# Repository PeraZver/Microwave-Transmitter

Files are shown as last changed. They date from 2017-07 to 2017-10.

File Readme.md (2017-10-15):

# Microwave Transmitter

30 - 6000 MHz 10 dBm Transmitter based on MAX2871 synthesizer. 
Controlled by Teensy 3.2. 

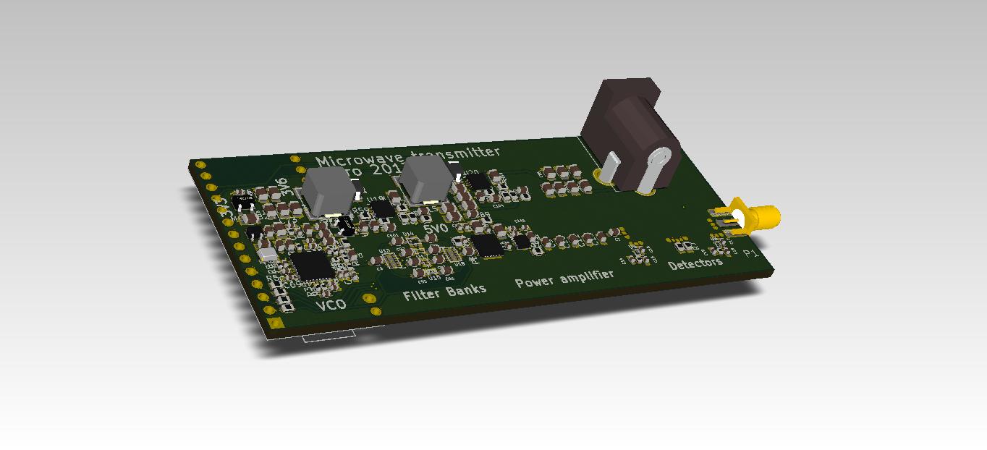
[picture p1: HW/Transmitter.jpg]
MW-Tx


Some parts of the circuit design based on H. Forsten's home made VNA. The microwave transmitter consists of following blocks:

 * **Synthesizer** is based on MAX2871 chip (PLL with integrated VCO) and its loop filter. This guy is able to synthesize frequencies from 25 MHz to 6 GHz.
 * **Filter bank** that makes sure no harmonics are generated in GHz range.
 * **Amplification** block that uses programmable attenuation for the gain control and 12 dB power amplifier TRF37A75.
 * **Coupler and RSSI detectors** that measure emitted and reflected power, of course. 
 * **Teensy 3.2** that controls the synthesizer, selects filter switches, controls the attenuation and AD converts measured power from the RSSI detectors and sends all of data to PC. 
 * **Power supply** that scales 12V input to 5V, 3.6V, 3.3V and 1.8V. 

User's guide of Microwave Transmitter is available at [Github repo's wiki](https://github.com/PeraZver/Microwave-Transmitter/wiki).

Development log of the Microwave Transmitter is documented at [Hackaday.io](https://hackaday.io/project/20350-microwave-transmitter).

Pero, February 2017
(https://www.helentronica.com)

[3d]: https://github.com/PeraZver/Microwave-Transmitter/blob/master/HW/Transmitter.jpg

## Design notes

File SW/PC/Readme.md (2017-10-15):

# Using python script

Just run it, either from the terminal or from your Python IDE. 
In the code, change proper COM port before the run.

Use following commands:
  * `g` - read MAX2871 register content
  * `rt` - read MAX2871 ADC set to temperature readout
  * `rv` - read MAX2871 ADC set to VCO voltage readout
  * `e` - activate RF output
  * `d` - deactivate RF output
  * `px` - sets the power of RF output, where {x} can be 1,2,3 or 4.
  * `fx` - selects the filter, where {x} can be 1,2,3 or 4.

  To change frequency settings, use following commands:
   * `N x` - set integer divider where x is between 16 and 65535.
   * `M x` - set fractional modulus where x is between 2 and 4095.
   * `F x` - set fractional divider where x is between 1 and M.
   * `R x` - set reference divider where x is between 1 and 1023.
   * `D x` - set output divider where x is between 1 and 7.

 Frequency can be easily set by two functions
   * `FINT x` - set sets frequency x in integer mode
   * `FFRAC x` - set sets frequency x in fractional mode

 To set the attentuation, use command:
   * `ATT x` - where x is attenuation in dB from 0 to 32 in steps of 0.25 dB. 

 Special spice is function `sweep`, that enables sweep of every parameter (but will work only with F and N):
  * `sweep x a b dt` - x can be N or F, a is lower limit, b is the upper and dt is time resolution in ms.

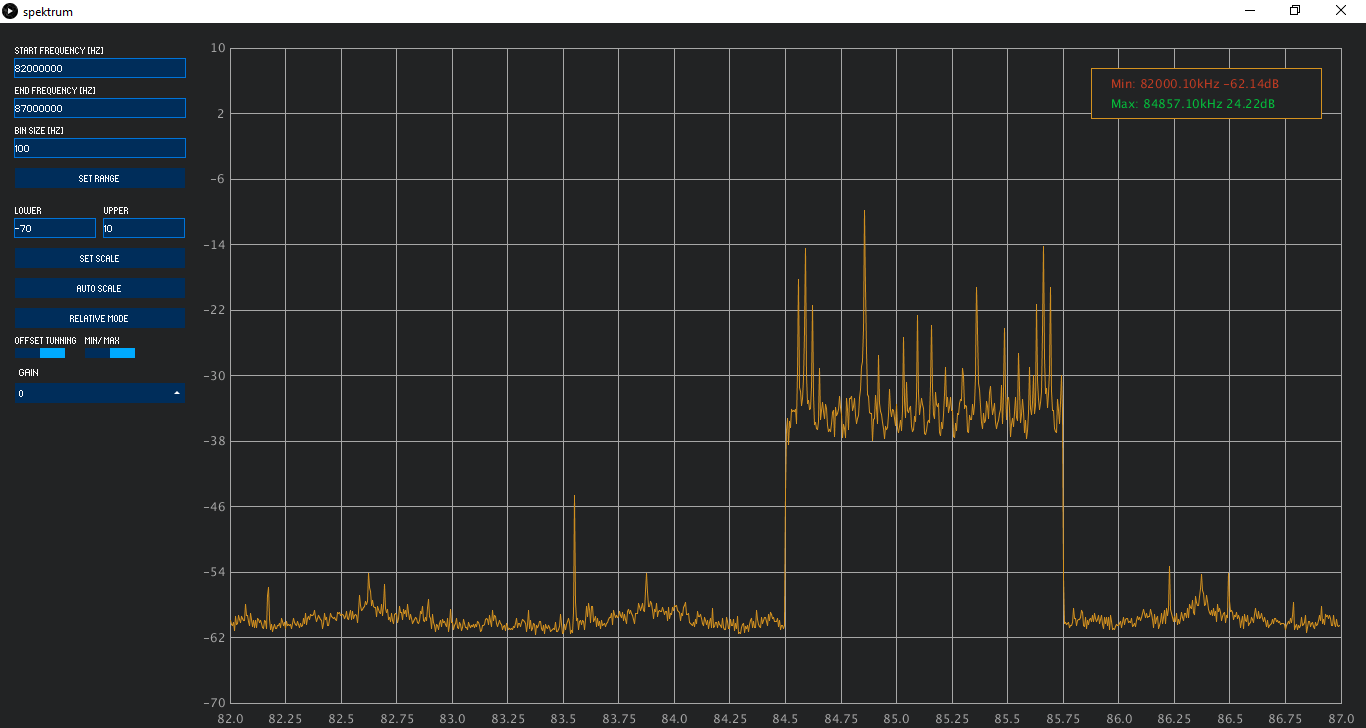
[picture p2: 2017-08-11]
Doc/Screenshots/spektrum_85MHz.png

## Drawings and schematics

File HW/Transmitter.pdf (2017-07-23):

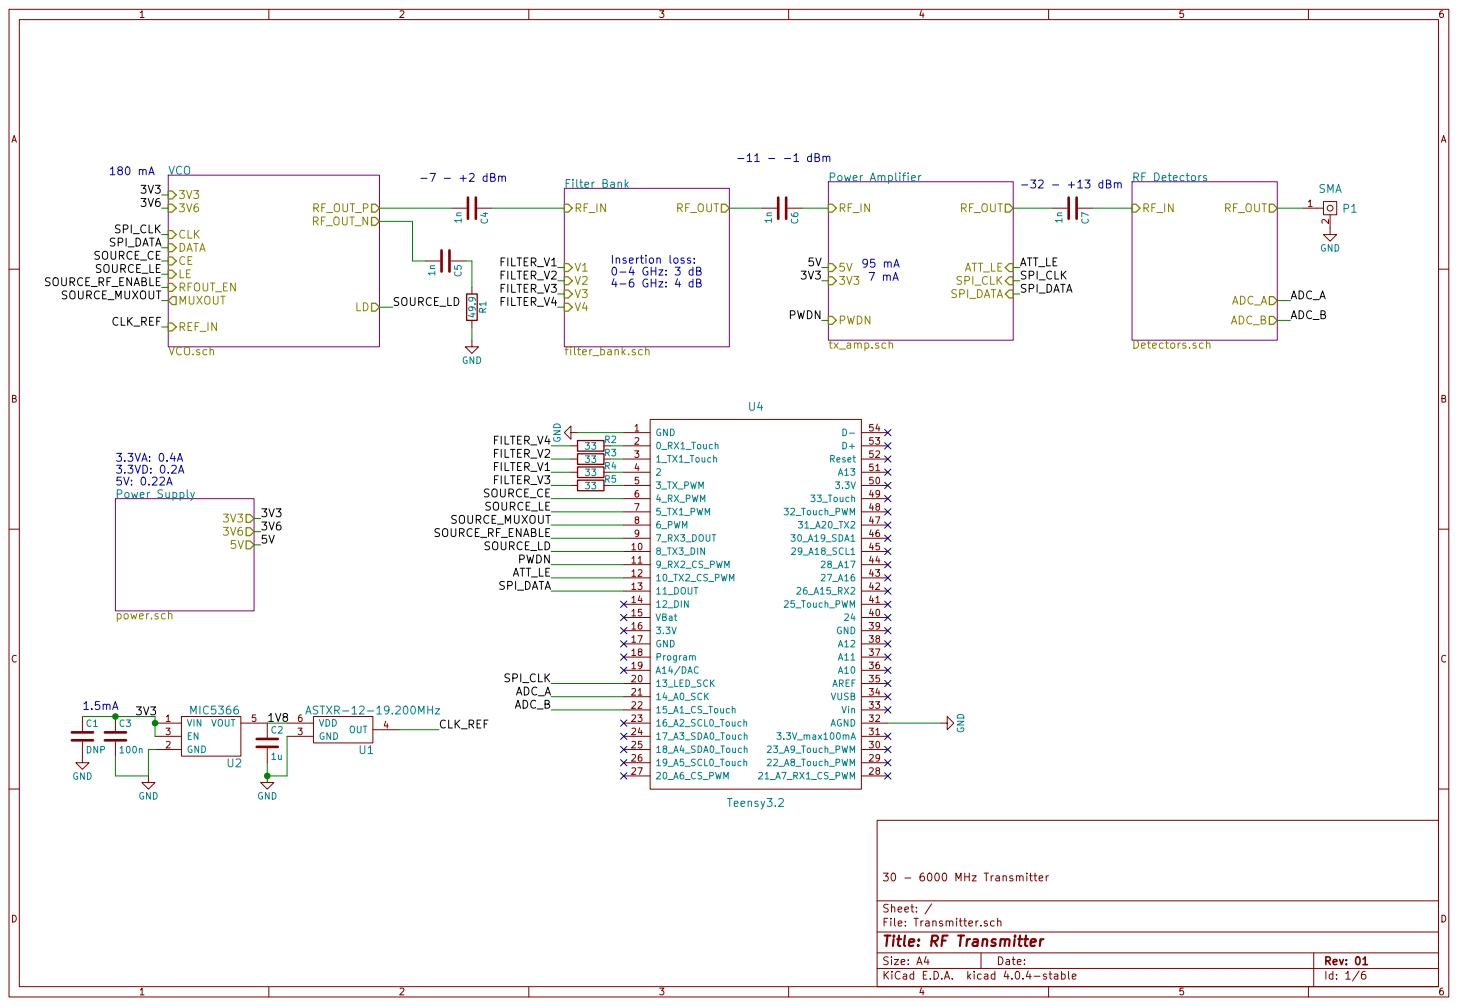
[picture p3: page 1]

Insertion loss: 0-4 GHz: 3 dB
4-6 GHz: 4 dB

Id: 1/6 Title: RF Transmitter File: Transmitter.sch Sheet: / 30 - 6000 MHz Transmitter

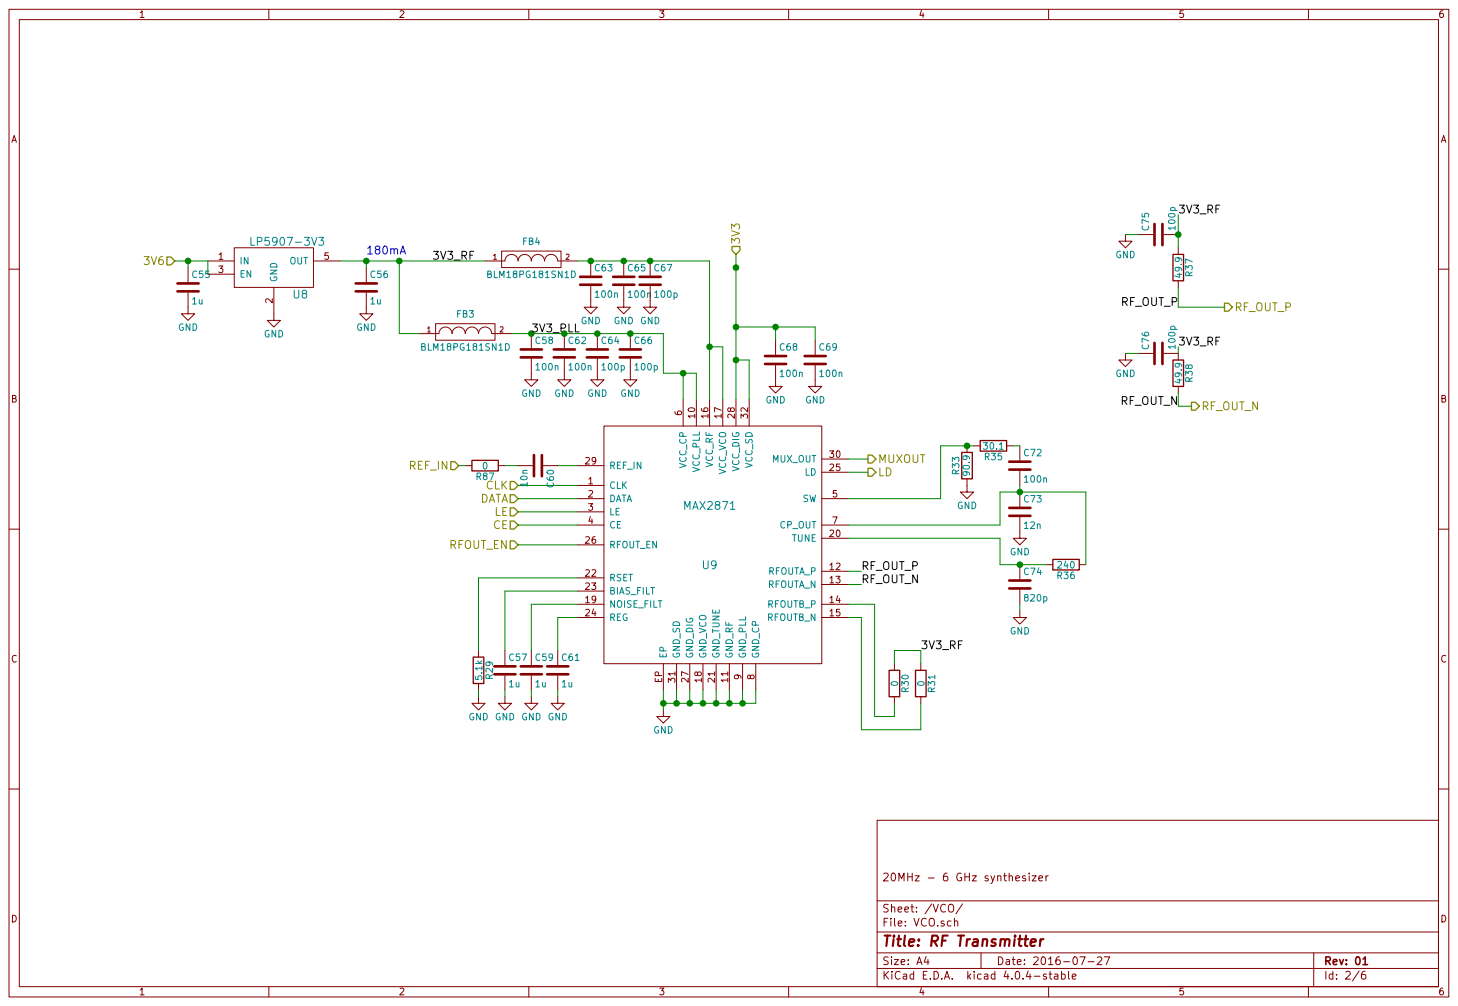
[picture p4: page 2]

100n GND GND GND GND GND

100n 5.1k R29 GND GND GND GND

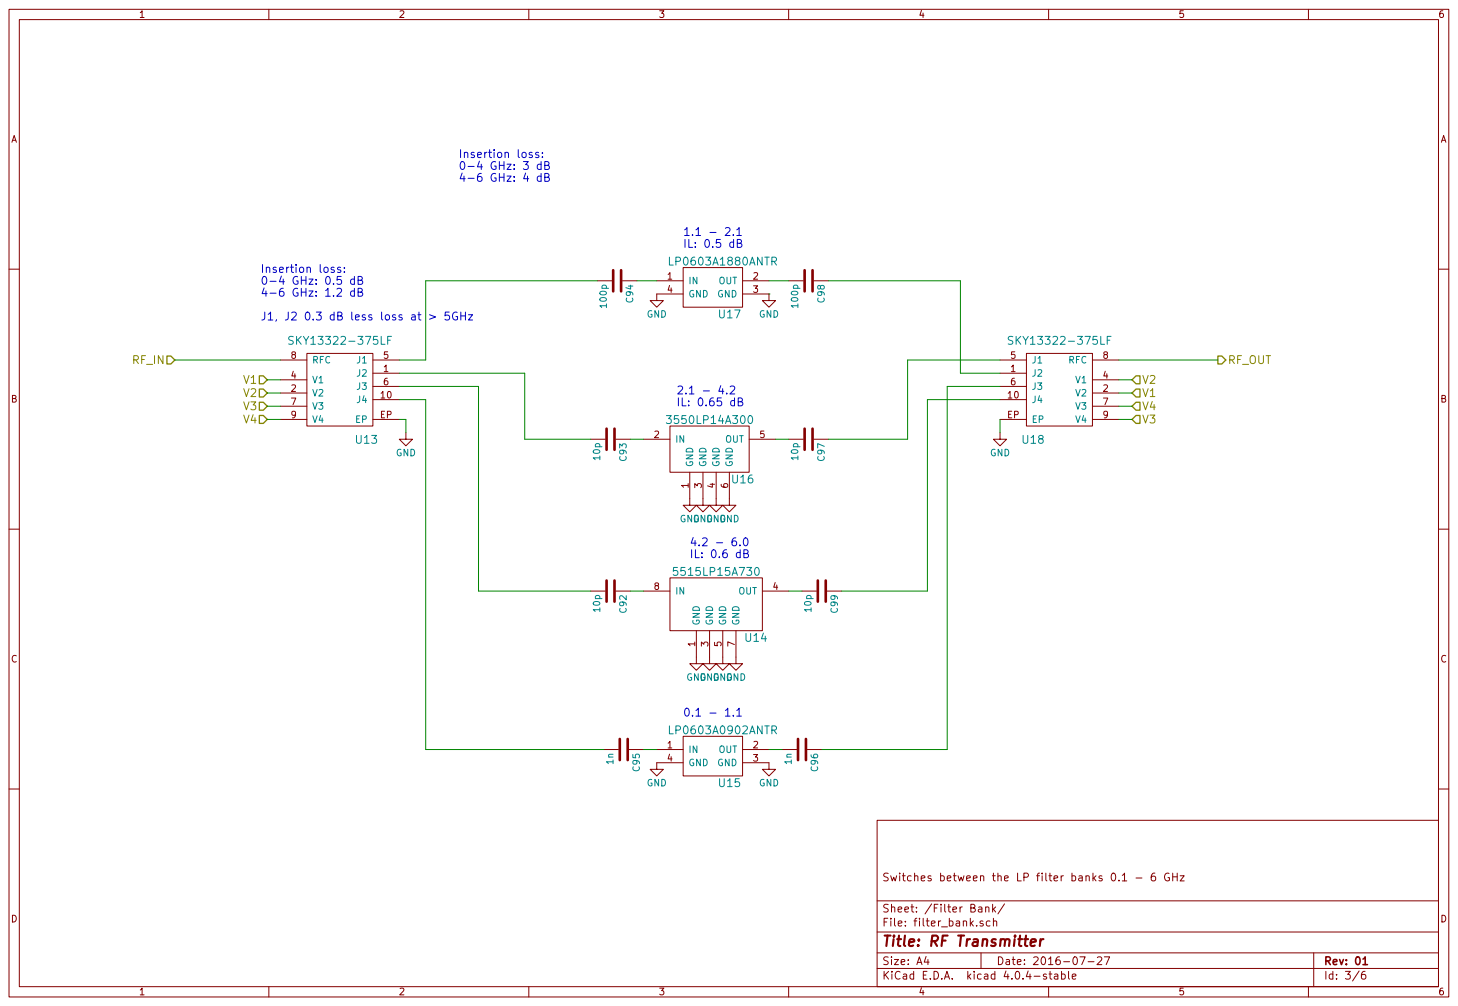
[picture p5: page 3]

Insertion loss: 0-4 GHz: 3 dB
4-6 GHz: 4 dB

Insertion loss: 0-4 GHz: 0.5 dB
4-6 GHz: 1.2 dB
J1, J2 0.3 dB less loss at > 5GHz

File: filter_bank.sch Sheet: /Filter Bank/ Switches between the LP filter banks 0.1 - 6 GHz

Id: 3/6 Title: RF Transmitter

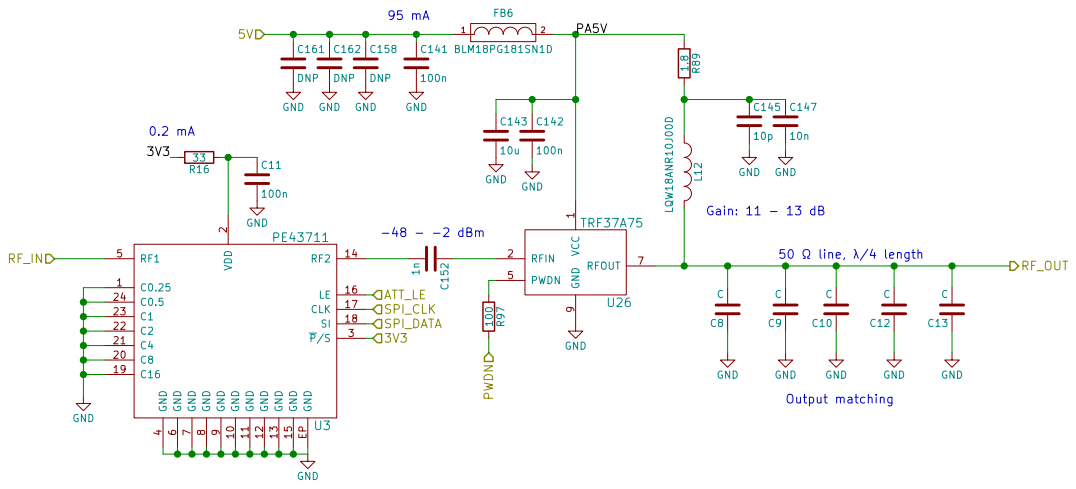
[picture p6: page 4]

1 RFIN 2 PWDN 5 RFOUT 7 GND

9 GND 10 C8 20 GND 11 C4 21 GND 12 C2 22 GND 13 C1 23 RF2 14 C0.5 24 GND 15

Sheet: /Power Amplifier/
File: tx_amp.sch
Id: 4/6 Title: RF Transmitter

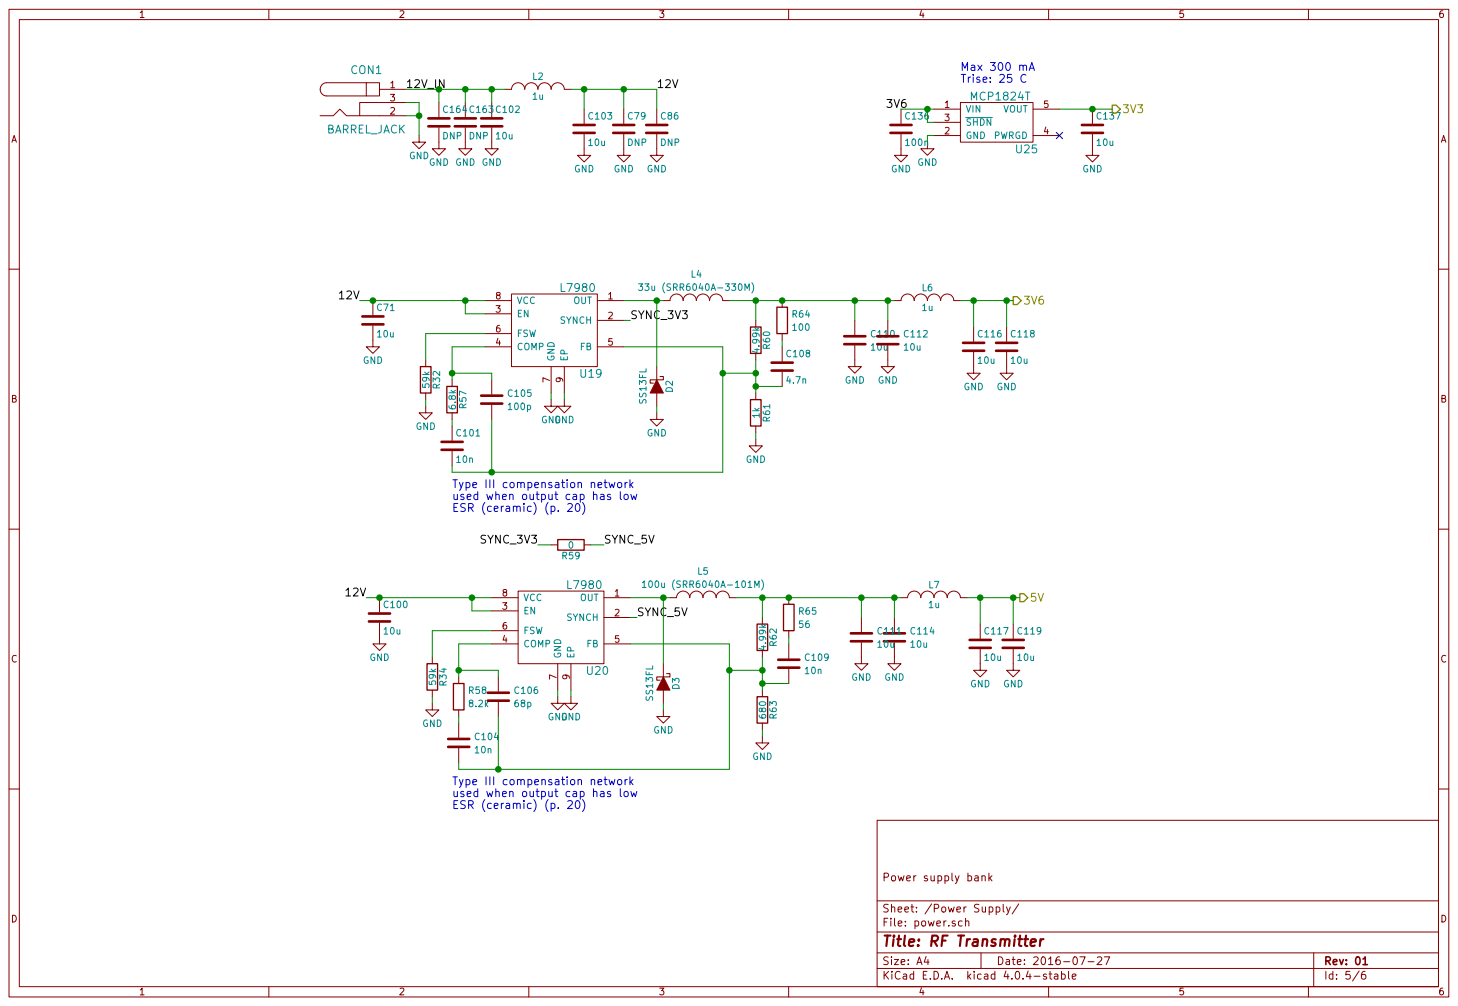
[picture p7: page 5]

C164 DNP GND Type III compensation network

used when output cap has low
ESR (ceramic) (p. 20)

Type III compensation network

Sheet: /Power Supply/
File: power.sch
Id: 5/6 Title: RF Transmitter

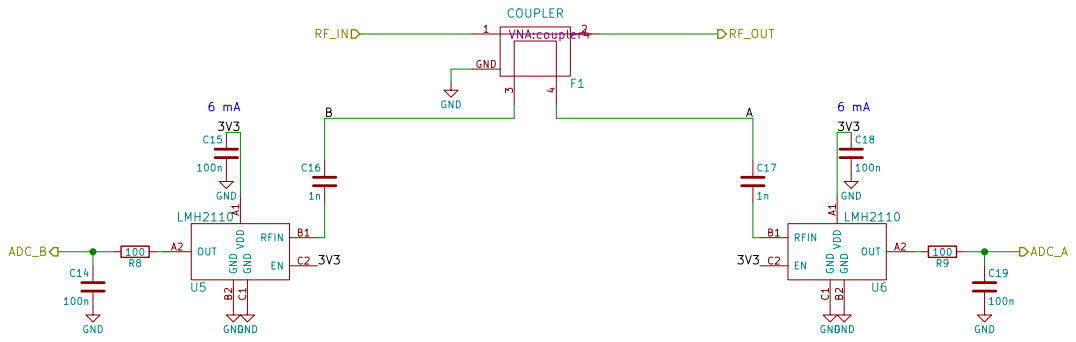
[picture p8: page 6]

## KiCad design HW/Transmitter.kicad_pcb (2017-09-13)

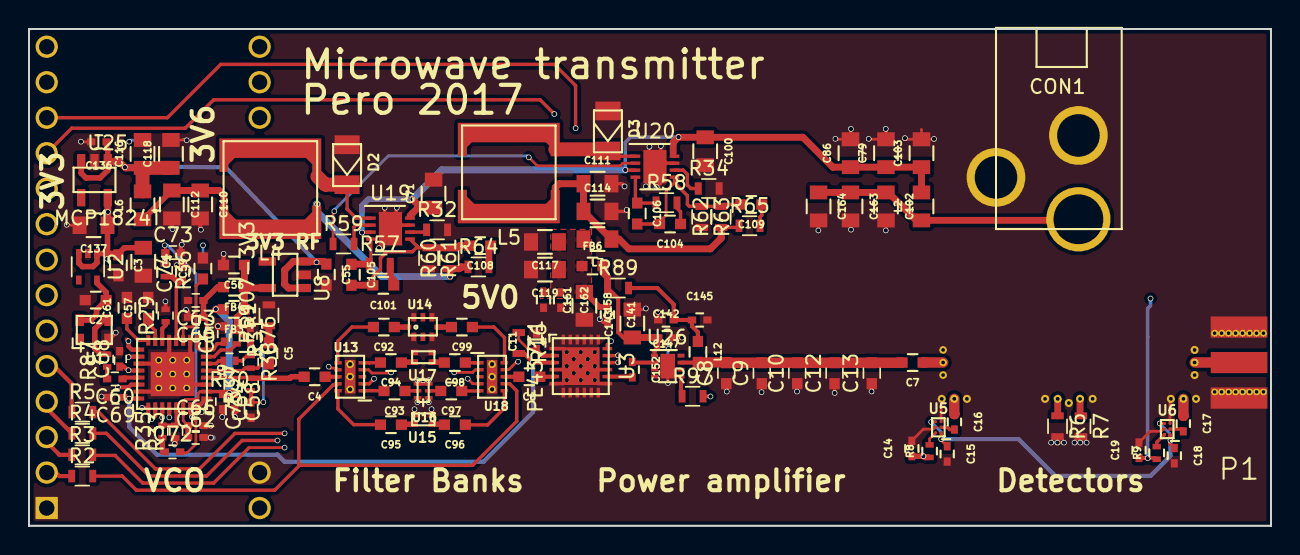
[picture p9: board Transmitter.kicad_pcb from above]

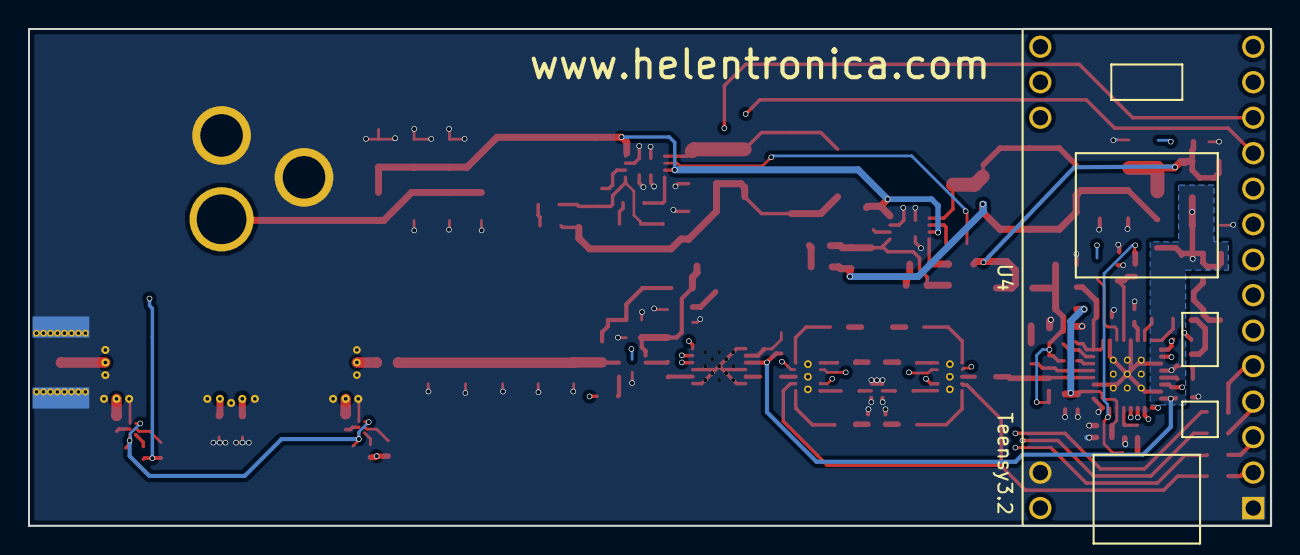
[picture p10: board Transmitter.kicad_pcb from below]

Board: 4 copper layers, 88.9 x 35.6 mm, 144 parts (2 on the bottom side), 98 nets.

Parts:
C1, C79, C86, C158, C163, C164: DNP; C_0805b
C2, C55, C56, C57, C59, C61: 1u; C_0603b
C3: 100n; C_0603b
C4, C5, C6, C7, C95, C96: 1n; C_0603b
C8, C9, C10, C12, C13: C; C_0603
C11, C14, C15, C18, C19, C136, C141, C142: 100n; C_0402b
C16, C17, C152: 1n; C_0402b
C58, C62, C63, C65, C68, C69, C72: 100n; C_0402
C60: 10n; C_0402
C64, C66, C67, C75, C76: 100p; C_0402
C71, C100, C102, C103, C110, C111, C112, C114, C116, C117, C118, C119, C137, C143: 10u; C_0805b
C73: 12n; C_0402
C74: 820p; C_0402
C92, C93, C97, C99: 10p; C_0603b
C94, C98, C105: 100p; C_0603b
C101, C104, C109: 10n; C_0603b
C106: 68p; C_0603b
C108: 4.7n; C_0603b
C145: 10p; C_0402b
C147: 10n; C_0402b
C161, C162: DNP; C_0402b
CON1: BARREL_JACK; EJ508A
D2, D3: SS13FL; SOD-123F
F3: COUPLER; coupler4
FB3, FB4, FB6: BLM18PG181SN1D; C_0603b
L2, L6, L7: 1u; C_0805b
L4: 33u (SRR6040A-330M); SRR6040A
L5: 100u (SRR6040A-101M); SRR6040A
L12: LQW18ANR10J00D; C_0603b
P1: SMA; CONSMA003.062
R1, R6, R7: 49.9; R_0603
R2, R3, R4, R5, R16: 33; R_0603
R8, R9: 100; R_0402b
R29: 5.1k; R_0402
R30, R31, R87: 0; R_0402
R32, R34: 59k; R_0603
R33: 90.9; R_0402
R35: 30.1; R_0402
R36: 240; R_0402
R37, R38: 49.9; R_0402
R57: 6.8k; R_0603
R58: 8.2k; R_0603
R59: 0; R_0603
R60, R62: 4.99k; R_0603
R61: 1k; R_0603
R63: 680; R_0603
R64, R97: 100; R_0603
R65: 56; R_0603
R89: 1.8; R_0603
U1: ASTXR-12-19.200MHz; ASTRX-12
U2: MIC5366; SOT-353_SC-70-5
U3: PE43711; VQFN-24
U4: Teensy3.2; Teensy30_31_32_LC
U5, U6: LMH2110; WFBGA-6
U8: LP5907-3V3; SOT-23-5
U9: MAX2871; TQFN-32
U13, U18: SKY13322-375LF; MLPD-10
U14: 5515LP15A730
U15: LP0603A0902ANTR; LP0603A0902
U16: 3550LP14A300
U17: LP0603A1880ANTR; LP0603A0902
U19, U20: L7980; DFN-8-1EP_3x3mm_Pitch0.5mm
U25: MCP1824T; SOT-23-5
U26: TRF37A75; DFN-8-1EP_2x2mm_Pitch0.5mm

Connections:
/1V8: C2.1, U1.6, U2.5
/3V3: C1.1, C3.1, C68.1, C69.1, C137.1, R16.2, U2.1, U2.3, U3.3, U9.28, U9.32, U25.5
/3V6: C55.1, C116.1, C118.1, C136.1, L6.2, U8.1, U8.3, U25.1, U25.3
/5V: C117.1, C119.1, C141.1, C158.1, C161.1, C162.1, FB6.1, L7.2
/ADC_A: C19.1, R9.1, U4.21
/ADC_B: C14.1, R8.1, U4.22
/ATT_LE: U3.16, U4.12
/CLK_REF: R87.2, U1.4
/FILTER_V1: R4.2, U13.4, U18.2
/FILTER_V2: R3.2, U13.2, U18.4
/FILTER_V3: R5.2, U13.7, U18.9
/FILTER_V4: R2.2, U13.9, U18.7
/Filter Bank/RF_IN: C4.1, U13.8
/Filter Bank/RF_OUT: C6.2, U18.8
/PWDN: R97.2, U4.11
/Power Amplifier/PA5V: C142.1, C143.1, FB6.2, R89.1, U26.1
/Power Amplifier/RF_IN: C6.1, U3.5
/Power Amplifier/RF_OUT: C7.2, C8.2, C9.2, C10.2, C12.2, C13.2, L12.2, U26.7
/Power Supply/12V: C71.1, C79.1, C86.1, C100.1, C103.1, L2.2, U19.3, U19.8, U20.3, U20.8
/Power Supply/12V_IN: C102.1, C163.1, C164.1, CON1.1, L2.1
/Power Supply/SYNC_3V3: R59.2, U19.2
/Power Supply/SYNC_5V: R59.1, U20.2
/RF Detectors/3V3: C15.1, C18.1, U5.A1, U5.C2, U6.A1, U6.C2
/RF Detectors/A: C17.1, F3.6
/RF Detectors/B: C16.1, F3.3
/RF Detectors/RF_IN: C7.1, F3.1
/RF Detectors/RF_OUT: F3.2, P1.1
/SOURCE_CE: U4.6, U9.4
/SOURCE_LD: U4.10, U9.25
/SOURCE_LE: U4.7, U9.3
/SOURCE_MUXOUT: U4.8, U9.30
/SOURCE_RF_ENABLE: U4.9, U9.26
/SPI_CLK: U3.17, U4.20, U9.1
/SPI_DATA: U3.18, U4.13, U9.2
/VCO/3V3_PLL: C58.1, C62.1, C64.1, C66.1, FB3.2, U9.6, U9.10
/VCO/3V3_RF: C56.1, C75.2, C76.2, FB3.1, FB4.1, R30.1, R31.1, R37.1, R38.1, U8.5
/VCO/RF_OUT_N: C5.2, R38.2, U9.13
/VCO/RF_OUT_P: C4.2, R37.2, U9.12
GND: C1.2, C2.2, C3.2, C8.1, C9.1, C10.1, C11.2, C12.1, C13.1, C14.2, C15.2, C18.2, C19.2, C55.2, C56.2, C57.2, C58.2, C59.2, C61.2, C62.2, C63.2, C64.2, C65.2, C66.2, C67.2, C68.2, C69.2, C71.2, C73.2, C74.2, C75.1, C76.1, C79.2, C86.2, C100.2, C102.2, C103.2, C110.2, C111.2, C112.2, C114.2, C116.2, C117.2, C118.2, C119.2, C136.2, C137.2, C141.2, C142.2, C143.2, C145.2, C147.2, C158.2, C161.2, C162.2, C163.2, C164.2, CON1.2, CON1.3, D2.2, D3.2, F3.GND, P1.2, R1.2, R6.2, R7.2, R29.2, R32.2, R33.1, R34.2, R61.2, R63.2, U1.3, U2.2, U3.1, U3.4, U3.6, U3.7, U3.8, U3.9, U3.10, U3.11, U3.12, U3.13, U3.15, U3.19, U3.20, U3.21, U3.22, U3.23, U3.24, U3.EP, U4.1, U4.32, U5.B2, U5.C1, U6.B2, U6.C1, U8.2, U9.8, U9.9, U9.11, U9.18, U9.21, U9.27, U9.31, U9.EP, U13.EP, U14.1, U14.3, U14.5, U14.7, U15.3, U15.4, U16.1, U16.3, U16.4, U16.6, U17.3, U17.4, U18.EP, U19.7, U19.9, U20.7, U20.9, U25.2, U26.9
unnamed: C5.1, R1.1
unnamed: C11.1, R16.1, U3.2
unnamed: C16.2, U5.B1
unnamed: C17.2, U6.B1
unnamed: C57.1, U9.23
unnamed: C59.1, U9.19
unnamed: C60.1, U9.29
unnamed: C60.2, R87.1
unnamed: C61.1, U9.24
unnamed: C63.1, C65.1, C67.1, FB4.2, U9.16, U9.17
unnamed: C72.1, R35.1
unnamed: C72.2, C73.1, R36.1, U9.7
unnamed: C74.1, R36.2, U9.20
unnamed: C92.1, U14.8
unnamed: C92.2, U13.6
unnamed: C93.1, U16.2
unnamed: C93.2, U13.1
unnamed: C94.1, U17.1
unnamed: C94.2, U13.5
unnamed: C95.1, U15.1
unnamed: C95.2, U13.10
unnamed: C96.1, U18.6
unnamed: C96.2, U15.2
unnamed: C97.1, U18.5
unnamed: C97.2, U16.5
unnamed: C98.1, U18.1
unnamed: C98.2, U17.2
unnamed: C99.1, U18.10
unnamed: C99.2, U14.4
unnamed: C101.1, R57.2
unnamed: C101.2, C105.2, C108.2, R60.2, R61.1, U19.5
unnamed: C104.1, R58.2
unnamed: C104.2, C106.2, C109.2, R62.2, R63.1, U20.5
unnamed: C105.1, R57.1, U19.4
unnamed: C106.1, R58.1, U20.4
unnamed: C108.1, R64.2
unnamed: C109.1, R65.2
unnamed: C110.1, C112.1, L4.2, L6.1, R60.1, R64.1
unnamed: C111.1, C114.1, L5.2, L7.1, R62.1, R65.1
unnamed: C145.1, C147.1, L12.1, R89.2
unnamed: C152.1, U26.2
unnamed: C152.2, U3.14
unnamed: D2.1, L4.1, U19.1
unnamed: D3.1, L5.1, U20.1
unnamed: F3.4, R6.1
unnamed: F3.5, R7.1
unnamed: R2.1, U4.2
unnamed: R3.1, U4.3
unnamed: R4.1, U4.4
unnamed: R5.1, U4.5
unnamed: R8.2, U5.A2
unnamed: R9.2, U6.A2
unnamed: R29.1, U9.22
unnamed: R30.2, U9.14
unnamed: R31.2, U9.15
unnamed: R32.1, U19.6
unnamed: R33.2, R35.2, U9.5
unnamed: R34.1, U20.6
unnamed: R97.1, U26.5

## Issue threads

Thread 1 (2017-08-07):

Switch not working in position 1

PeraZver, 2017-08-07:
Input switch SKY13322-375LF behaves weirdly when switched to position 1. Otherwise it works fine. Output switch no issues. Both issues weird when control signals are all low.

PeraZver, 2017-09-06:
Switch resoldered and works fine.

Closed 2017-09-06.

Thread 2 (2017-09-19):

RSSI Detectors not working

PeraZver, 2017-09-19:
I didn't manage to receive any meaningful signal from RSSI outputs. Two possible reasons for this:
a) Bad soldering of 6-ball BGA chips
b) Poor coupling from the main line.

Nothing I can do about it in this revision. In the next one, I'll try to put coupler and RSSI detectors on different board.

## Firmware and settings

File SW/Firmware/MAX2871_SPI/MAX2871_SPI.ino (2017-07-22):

/*  MAX2871 SPI Interface
  
  This example controls an MAX2871 synthesizer.
  
  MAX2871 serial interface contains six write-only and
  one read-only 32-bit registers. 
     
   The circuit:
  * CLK is pin 13
  * DATA OUT is pin 11
  * LE is pin 5
  * DATA IN is pin 12
  * CE is pin 6
  * RF EN is pin 7

 
Pero, June 2017
 
*/


// include the SPI library:
#include <SPI.h>

#define slaveSelectPin 5   //LE or slave select
#define chipEnablePin  4   // (CE)
#define clkPin         13  // clk pin
SPISettings MAX2871_SPISettings(1000000, MSBFIRST, SPI_MODE0);

char incomingChar = 0;  //Serial input

void setup() {
  delay(3000);
  Serial.begin(9600);
  Serial.println("MAX2871 SPI Interface");  
  Serial.println("v0.0");
  Serial.println("Pero, June 2017");
  Serial.println(" ");
  Serial.println(" ");
  // Enable chip
  pinMode(chipEnablePin, OUTPUT);
  digitalWrite(chipEnablePin, HIGH);
    
  // set the slaveSelectPin as an output:
  pinMode (slaveSelectPin, OUTPUT);
  digitalWrite (slaveSelectPin, HIGH);
  
  // initialize SPI:
  SPI.begin(); 
  Serial.println("SPI Initialized");
  
  MAX2871_Init ();
  Serial.println("MAX2871 Initialized");
  
}

void loop() {
  if(Serial.available() > 0) 
    incomingChar = Serial.read();
  
  //incomingChar = 'r';
  switch (incomingChar){
    
    case 'r':    
      MAX2871_Set_MUX(3);  // Set read function on MUX pin
      while(1){
        MAX2871_Read();
        delay(1000);
      }
      break;
      
    default:
      MAX2871_Set_MUX(1);
      delay(2000);
      MAX2871_Set_MUX(2);
      delay(2000);
  }
}

void MAX2871_Init (){
//Upon power-up, the registers should be programmed
//twice with at least a 20ms pause between writes. The first
//write ensures that the device is enabled, and the second
//write starts the VCO selection process. Recommended to
//turn-off the outputs during this sequence and then turn-on
//the outputs using RFA_EN, RFB_EN. 

//Register programming order should be address 0x05,
//0x04, 0x03, 0x02, 0x01, and 0x00. 

 uint32_t regInitValues[6] = {0x00000005, 
                              0x60000004,
                              0x00000003,
                              0x00000002,
                              0x00000001,
                              0x0};

 // Writing 2 times
 for (int j = 0; j < 2; j++){
  for (int i = 0; i < 6; i++)   // 6 write registers
      MAX2871_SPI_tx (regInitValues[i]);  //Everything to 0.
  delay(20);
  }
      
}

void MAX2871_Read(){
  /*
    Register 0x06 can be read back through the MUX pin.
    The user must set MUX (register 5, bit 18 and register
    2, bits 28:26) = 1100. To begin the read sequence, set
    LE to logic-low, send 32 periods of CLK, and set LE to
    logic-high. While the CLK is running, the DATA pin can
    be held at logic-high or logic-low for 29 clocks, but the
    last 3 bits must be 110 to indicate register 6, then set LE
    back to logic-high after the 32nd clock. Finally, send 1
    period of the clock. The MSB of register 0x06 appears
    after the rising edge of the next clock and continues to
    shift out for the next 29 clock cycles (Figure 2). After the
    LSB of register 0x06 has been read, the user can reset
    MUX register = 0000.
   */
   uint32_t spi_data = 0;
   uint8_t spi_packet[4] = {0}; 
   signed char i;
   Serial.println("Reading data from MAX2871.");
   
   MAX2871_SPI_tx(spi_data | 6);   // "... last 3 bits must be 110 to indicate register 6." 

   SPI.beginTransaction(MAX2871_SPISettings);  // start new clock sequence. No need to change SS to low.
   for ( i = 0; i < 4; i++)   {
       spi_packet[i] = SPI.transfer(0x06);   // read from SPI shift register 4 times
   }
   SPI.endTransaction();    
  
  Serial.println("Data read:");
  for ( i = 0; i < 4; i++){
     Serial.println(spi_packet[i], HEX);
     spi_data |= spi_packet[i];  
     if ( i != 3)
         spi_data = spi_data << 8;
  }
  Serial.println(spi_data << 2, HEX);
  Serial.println("Reading done!");   
  //MAX2871_Set_MUX(0);  // Reset MUX pin
  
  
}

void MAX2871_Set_MUX(byte MUXSet){
  
/* Bits MUX[3:0] set the MUX pin.
 *  0001: VDD
 *  0010: GND
 *  1100: SPI read operation
 *  
 *  MUX[3] is bit 18 in reg5, and MUX[2:0] are bits 28:26 in reg2.
 */

 uint32_t spi_data = 0; // 32-bits for SPI consist of 29 data bits and 3 address bits.
 
 switch( MUXSet ){

    case 0:  //Set MUX to High Z
         Serial.println("setting MUX to High Z ...");
         // Set all to zero
         MAX2871_SPI_tx( spi_data | 0x02);
         MAX2871_SPI_tx( spi_data | 0x05);
         break;
         
    case 1:   // Set MUX to VDD
         Serial.println("setting MUX to VDD ...");
         spi_data |= (1 << 26);
         MAX2871_SPI_tx(spi_data | 0x02);
         break;
         
    case 2:  // Set MUX to GND
         Serial.println("setting MUX to GND ...");
         spi_data |= (1<<27);
         MAX2871_SPI_tx(spi_data | 0x02);
         break;
         
    default:  //Set MUX to "read"
         Serial.println("setting MUX to SPI read ...");
         spi_data |= (1<<18);
         MAX2871_SPI_tx(spi_data | 0x05);         
         spi_data = 0;    
         spi_data |= (1<<28);
         MAX2871_SPI_tx(spi_data | 0x02);
         
 }
}

void MAX2871_SPI_tx(uint32_t spi_data){
  /*
  This function takes 32-bit data and parses it on four 8-bit packets that Teensy transmitts. The 29 most-significant
  bits (MSBs) are data, and the three least-significant bits (LSBs) are the register address. 
   */

    signed char i = 0;
    uint8_t spi_package[4] = {0};
    // store 32-bit integer into 4 bytes
    for ( i = 0; i < 4; i++) {
       spi_package[i] = (spi_data & (0xFF << 8*i)) >> ( 8*i ) ;
       //Serial.println(spi_package[i], HEX);
    }
    
    Serial.println("Sending data: "); 
    Serial.println(spi_data, HEX);
    digitalWrite(slaveSelectPin,LOW);   
    SPI.beginTransaction(MAX2871_SPISettings);
     
    for ( i = 3; i >= 0; i--)
         SPI.transfer(spi_package[i]); 
          
    digitalWrite(slaveSelectPin,HIGH);
    SPI.endTransaction();  
    Serial.println("SPI transmission done!");
    delay(20);
}
  

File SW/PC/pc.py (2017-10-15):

# -*- coding: utf-8 -*-
#! python
"""
PC Interface with my Teensy/MAX2871 based 
microwave transmitter via serial port. 


Created on Wed Sep 06 22:33:43 2017

@author: Pero_2912
"""
import serial
import sys
import bitstring as bit
#import argparse
#import ast
#import time


f_REF = 19.2  # Reference frequency
params = {'R':1, 'N':200, 'F':0.0, 'M':100, 'D':5}  # frequency settings parameters
f_PDF = f_REF/params['R'] 


BAUDRATE = 9600
PARITY = False
#Configures serial port
def configure_serial(serial_port):
    return serial.Serial(
        port=serial_port,
        baudrate=BAUDRATE,
        parity=serial.PARITY_EVEN if PARITY else serial.PARITY_NONE,
        stopbits=serial.STOPBITS_TWO,
        bytesize=serial.EIGHTBITS,
        timeout=0.85)
      
def check_frequency (freq_dict):
# Function that calculates frequency based on PLL parameters 
# First test if we're somewhere where it's not allowed to be in   
    global f_PDF 
    if (freq_dict['R'] < 1) | (freq_dict['R'] > 1023):
        print 'R must be between 1 and 1023'
        return 0    
    if (freq_dict['N'] < 16) | (freq_dict['N'] > 65535):
        print 'N must be between 16 and 65535'
        return 0
    if (freq_dict['M'] < 2) | (freq_dict['M'] > 4095):
        print 'M must be between 2 and 4095'
        return 0
    if (freq_dict['F'] > freq_dict['M']):
        print 'F must be lower than M'
        return 0
# Calculate frequency from the given params        
    f_PDF = f_REF/freq_dict['R']
# Now check if N is somewhere where we won't be able to control VCOs.
    N_min = int(round(3000/f_PDF))
    N_max = int(round(6000/f_PDF))
    if ((freq_dict['N'] < N_min) | (freq_dict['N'] > N_max)):
        print 'N must be between '+ str(N_min) + ' and '+ str(N_max)
        return 0
    
    f_VCO = (freq_dict['N'] + freq_dict['F']*1.0/freq_dict['M'])*f_PDF
    f_RFOUT = f_VCO / (2**freq_dict['D'])
    print 'f_PDF is ' + str(round(f_PDF,4)) + ' MHz'
    print 'f_VCO is ' + str(f_VCO) + ' MHz'
    print 'f_RFOUT is ' + str(f_RFOUT) + ' MHz'
    return 1
    

    
def select_D(freq):
#    Selects D parameter based on desired frequency output
    if   3000 < freq <= 6000:
        return 0
    elif 1500 < freq <= 3000:
        return 1
    elif 750  < freq <= 1500:
        return 2    
    elif 375  < freq <= 750:
        return 3    
    elif 187.5 < freq <= 375:
        return 4
    elif 93.75 < freq <= 187.5:
        return 5
    elif 46.875 < freq <= 93.75:
        return 6        
    elif 23.5 < freq <=  46.875:
        return 7
        
def set_frequency_INT(freq):
    # sets  integer mode paramteres for given frequency
    D = select_D(freq) # we need parameter D first
    f_VCO = freq * 2**D  # this is what VCO will need to generate    
    N = int(f_VCO/f_PDF)
    return N, D

def set_frequency_FRAC(freq):
    # sets  integer mode paramteres for given frequency
    D = select_D(freq) # we need parameter D first
    f_VCO = freq * 2**D  # this is what VCO will need to generate    
    N = int(f_VCO/f_PDF)
    F = int((f_VCO/f_PDF - N)*params['M'])
    return N, D, F


def set_param_sweep(args):
#    returns command that starts given parameter sweep
    param = args[1]
    start = args[2]
    stop  = args[3]
    if (len(args) == 5):
        td = args[4]
    else:
        td = '10'    
    return ('s'+ param + start + 'a'+ stop +'a' + td +'a')
    
def freq_sweep(f_start, f_stop):
#    set frequency sweep from f_start to f_stop
    N_start, D_start = set_frequency_INT(f_start)
    N_stop, D_stop = set_frequency_INT(f_stop)
    return (set_param_sweep(('sweep','N', str(N_start), str(N_stop))))

        
def read_registers(ser):
# Reads and parses registers from MAX2871
    ser.write('g')
    while(True):
        line = ser.readline().strip()
        if line == 'MAX2871 Registers printout:':
            break
    print line
    for i in range(0,6):
        line = ser.readline()
        print 'Register ' + str(i)
        parse_register(line.strip(), i)
        print ' '
#    Update paramters that set frequency            
    check_frequency(params)

def parse_register(line, i):
#parses each register and displays values in human form  
        # if register has first bits equal to 0, Teensy will 
        # send data without them. That's why I fill like this
        while (len(line) < 8): 
            line = '0'+line
        print line
        reg = bit.BitArray(hex=line)
        #examine registers
        if (i == 0):
            print 'Integer mode: ' + str(reg[0])
            print 'Integer divider N: ' + str(reg[1:17].uint)
            print 'Fraction divider F: ' + str(reg[17:29].uint)
            params['N'] = reg[1:17].uint
            params['F'] = reg[17:29].uint
            
        elif (i == 1):
            print 'Fraction Modulus M: ' + str(reg[17:29].uint)
            params['M'] = reg[17:29].uint
            
        elif (i == 2):
            print 'Reference divider R: ' + str(reg[8:18].uint)
            print 'Reference DBR: ' + str(reg[6])
            print 'Reference DIV2: ' + str(reg[7])
            params['R'] = reg[8:18].uint
            
        elif (i == 4):
            print 'Output divider DIVA: ' + str(reg[9:12].uint)
            print 'Output power RFOUTA: ' + str(3*reg[27:29].uint - 4) + ' dBm'
            print 'Output power RFOUTA: ' + str(3*reg[24:26].uint - 4) + ' dBm'
            print 'RFOUTA enabled: ' + str(reg[26])
            print 'RFOUTB enabled: ' + str(reg[23])
            params['D'] = reg[9:12].uint
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

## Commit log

2017-07-22 add hw design files
    [Detectors.sch, Transmitter.kicad_pcb, Transmitter.sch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]
2017-07-23 Started working with temperature read.
2017-07-26 fixed temp & vtune readout
    [MAX2871.h, MAX2871_Temperature.ino]
2017-07-26 SPI init separate function
2017-07-27 made cpp file and test for filter switch
2017-08-11 add filter selection from serial terminal
2017-08-19 add power control over serial
2017-08-20 char array input for power and filter selection
2017-09-13 implemented sweep in firmware
    [Transmitter.kicad_pcb]
